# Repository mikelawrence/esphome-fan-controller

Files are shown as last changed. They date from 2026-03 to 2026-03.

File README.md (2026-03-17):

# ESPHome RGBCCT LED Controller

<p align="center">
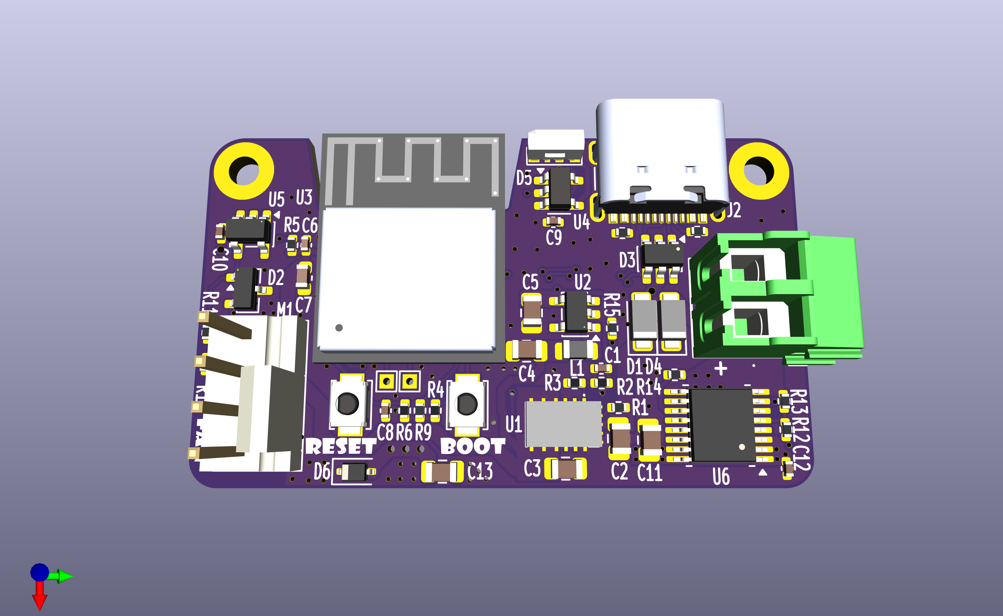
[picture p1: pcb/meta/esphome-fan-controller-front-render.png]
  
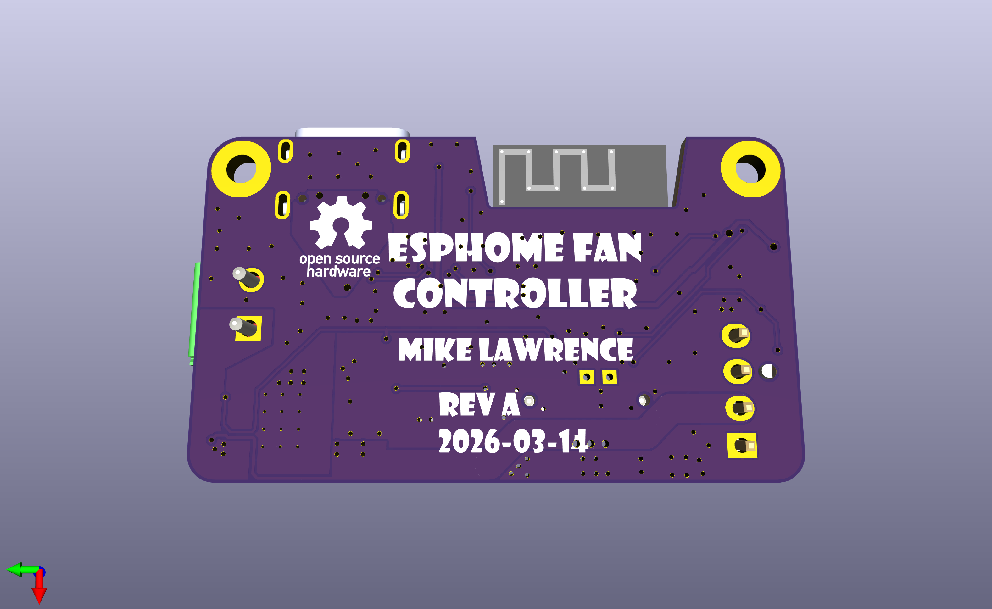
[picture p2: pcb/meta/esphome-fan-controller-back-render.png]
  
</p>

This is a simple ESP32-C3 based fan controller design to support 4-pin computer fans from 5V to 24V at up to 2 amps. Fan tachometer is supported.

## Web Installation

Goto [Github Pages](https://mikelawrence.github.io/esphome-fan-controller/) if you want to install a prebuilt image and receive automatic update notifications via Home Assistant.

## Status

* **Rev -:** Ordered boards from JLCPCB. Ordered parts from Mouser and Digikey. Board is assembled but there is a problem with the 5V Power Supply. Wait for Rev A.
* **Rev A:** Coming soon!

## Schematic

<p align="center">
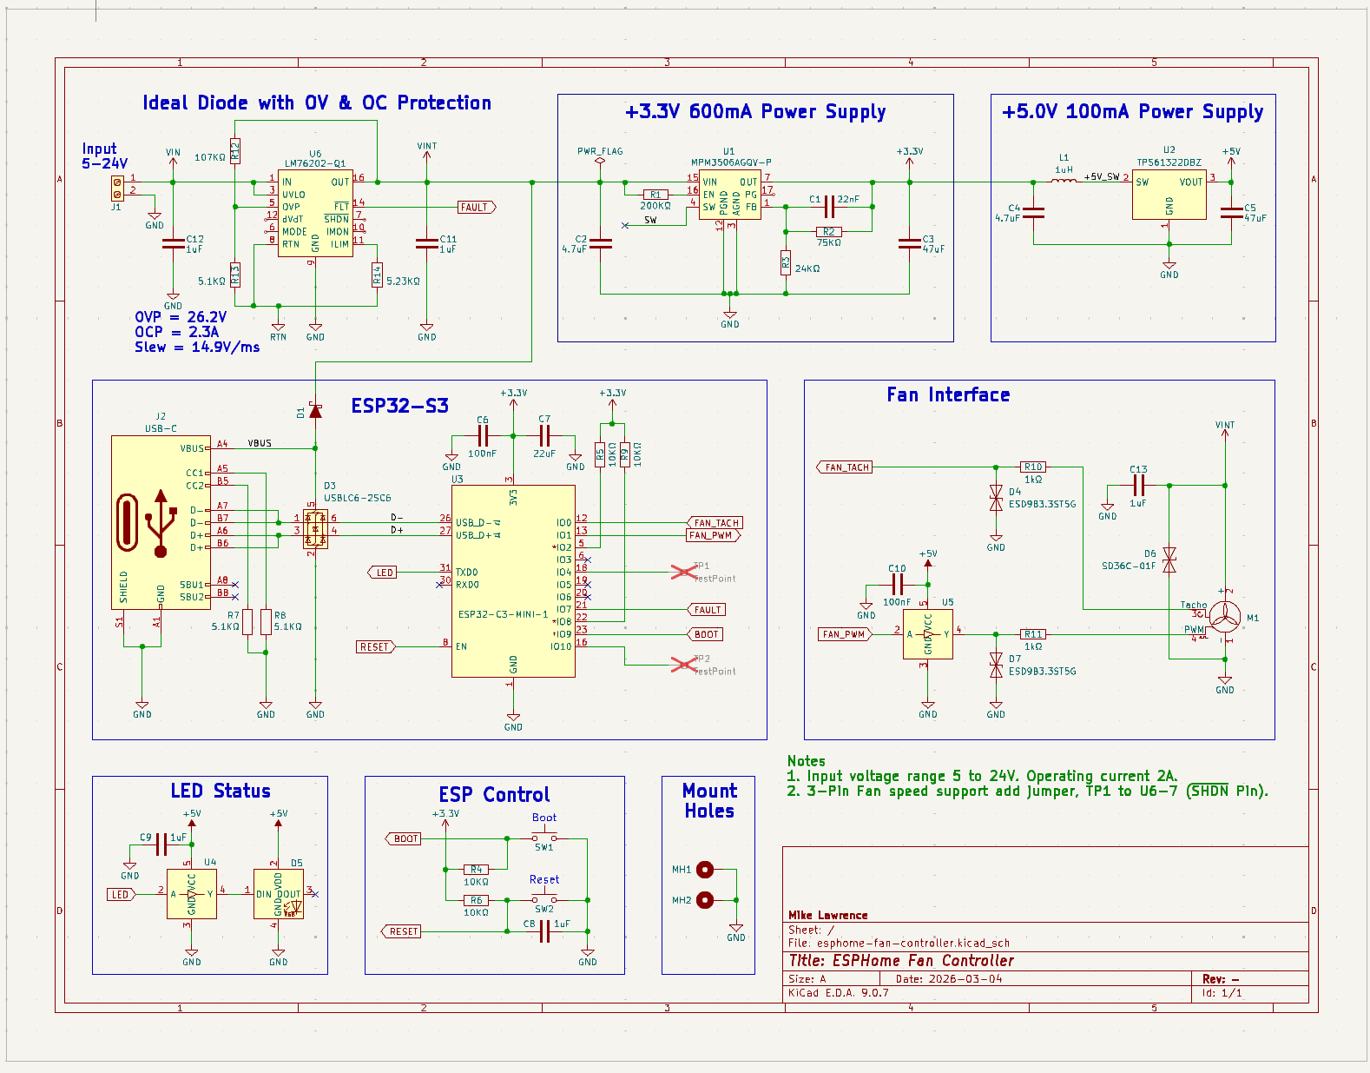
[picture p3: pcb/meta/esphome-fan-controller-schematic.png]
     <br />
    Schematic
</p>

## Bill of Materials

<p align="center">
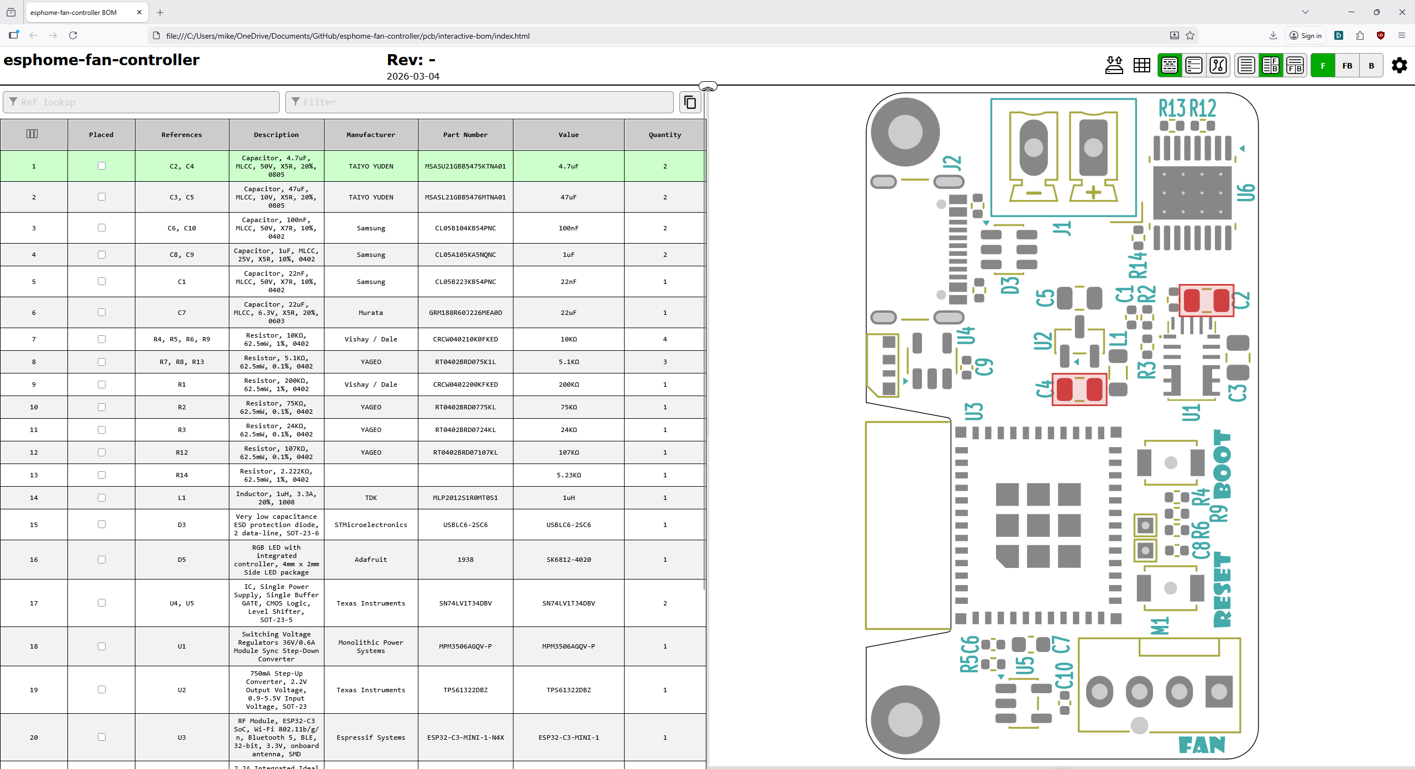
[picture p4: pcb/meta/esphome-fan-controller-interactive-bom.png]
     <br />
    Interactive BOM
</p>

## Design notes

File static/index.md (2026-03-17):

Sensor

# Web Installation

Use the button below to install pre-built firmware directly to your hardware via USB. You must use Google Chrome or Microsoft Edge to program your device. Firefox does not work.

| &nbsp; &nbsp; &nbsp; &nbsp; &nbsp; For 4-Pin Fans &nbsp; &nbsp; &nbsp; &nbsp; &nbsp; | &nbsp; &nbsp; &nbsp; &nbsp; &nbsp; For 3-Pin Fans &nbsp; &nbsp; &nbsp; &nbsp; &nbsp; |
| :---: | :---: |
| <esp-web-install-button manifest="firmware/fan-controller-4pin.manifest.json"></esp-web-install-button> | Coming Soon |

<script type="module" src="https://unpkg.com/esp-web-tools@10/dist/web/install-button.js?module"></script>

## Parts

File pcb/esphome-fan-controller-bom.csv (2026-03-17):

Qty | Reference | Value | Description | Datasheet | Footprint | DNP | Manufacturer | Part Number
1 | C1 | 22nF | Capacitor, 22nF, MLCC, 50V, X7R, 10%, 0402 | ~ | Capacitor_SMD:C_0402_1005Metric |  | Murata | GRM155R71H223KA12J
1 | C7 | 22uF | Capacitor, 22uF, MLCC, 6.3V, X5R, 20%, 0603 | ~ | Capacitor_SMD:C_0603_1608Metric |  | Murata | GRM188R60J226MEA0D
2 | C11,C13 | 1uF | Capacitor, 1uF, MLCC, 50V, X5R, 20%, 0805 | ~ | Capacitor_SMD:C_0805_2012Metric |  | YAGEO | CC0805MKY5V9BB105
2 | C2,C4 | 4.7uF | Capacitor, 4.7uF, MLCC, 50V, X5R, 20%, 0805 | ~ | Capacitor_SMD:C_0805_2012Metric |  | TAIYO YUDEN | MSASU21GBB5475KTNA01
2 | C3,C5 | 47uF | Capacitor, 47uF, MLCC, 10V, X5R, 20%, 0805 | ~ | Capacitor_SMD:C_0805_2012Metric |  | TAIYO YUDEN | MSASL21GBB5476MTNA01
3 | C6,C10,C12 | 100nF | Capacitor, 100nF, MLCC, 50V, X7R, 10%, 0402 | ~ | Capacitor_SMD:C_0402_1005Metric |  | Samsung | CL05B104KB54PNC
2 | C8,C9 | 1uF | Capacitor, 1uF, MLCC, 25V, X5R, 10%, 0402 | ~ | Capacitor_SMD:C_0402_1005Metric |  | Samsung | CL05A105KA5NQNC
1 | D2 | ESDS452 | 5.5-V Bi-Directional TVS Diode | https://www.ti.com/lit/ds/symlink/esds452.pdf | Package_TO_SOT_SMD:SOT-23 |  | Texas Instruments | ESDS452DBZR
1 | D3 | USBLC6-2SC6 | Very low capacitance ESD protection diode, 2 data-line, SOT-23-6 | https://www.st.com/resource/en/datasheet/usblc6-2.pdf | Package_TO_SOT_SMD:SOT-23-6 |  | STMicroelectronics | USBLC6-2SC6
1 | D5 | SK6812-4020 | RGB LED with integrated controller, 4mm x 2mm Side LED package | https://cdn-shop.adafruit.com/product-files/4691/4691_SK68XX_SIDE_REV.04_EN_1_.pdf | SK6812-4020:SK6812-4020 |  | Adafruit | 4691
1 | D6 | SD36C-01F | 36V, 450W Discrete Bidirectional TVS Diode, SOD-323 | https://www.littelfuse.com/~/media/electronics/datasheets/tvs_diode_arrays/littelfuse_tvs_diode_array_sd_c_datasheet.pdf.pdf | Diode_SMD:D_SOD-323 |  | Littelfuse | SD36C-01FTG
2 | D1,D4 | SS2FH6HM3/H | 40V 2A Schottky Barrier Rectifier Diode, SMF(DO-219AB) | https://www.vishay.com/docs/87731/ss2fh6.pdf | Diode_SMD:D_SMF |  | Vishay | SS2FH6HM3/H
1 | J1 | Screw_Terminal_01x02 | Generic screw terminal, single row, 01x02, script generated (kicad-library-utils/schlib/autogen/connector/) | https://www.phoenixcontact.com/en-us/products/printed-circuit-board-terminal-pta-15-2-35-1988956 | 1984769:1984769 |  | Phoenix Contact | 1988956
1 | J2 | USB-C | Connector, USB 2.0, 16P, Type-C, Receptacle | https://www.usb.org/sites/default/files/documents/usb_type-c.zip | TYPE-C-31-M-12:HRO_TYPE-C-31-M-12 |  | Phoenix Contact | 1332645
1 | L1 | 1uH | Inductor, 1uH, 3.3A, 20%, 1008 | ~ | Inductor_SMD:L_0805_2012Metric |  | TDK | MLP2012S1R0MT0S1
1 | M1 | Fan_CPU_4pin | CPU Fan, tacho output, PWM input, 4-pin connector | http://www.formfactors.org/developer%5Cspecs%5Crev1_2_public.pdf | Connector:FanPinHeader_1x04_P2.54mm_Vertical |  | Molex | 47053-1000
1 | R1 | 200KΩ | Resistor, 200KΩ, 62.5mW,100PPM, 1%, 0402 | ~ | Resistor_SMD:R_0402_1005Metric |  | Vishay / Dale | CRCW0402200KFKED
1 | R2 | 75KΩ | Resistor, 75KΩ, 62.5mW, 25PPM, 0.1%, 0402 | ~ | Resistor_SMD:R_0402_1005Metric |  | YAGEO | RT0402BRD0775KL
1 | R3 | 24KΩ | Resistor, 24KΩ, 62.5mW, 25PPM, 0.1%, 0402 | ~ | Resistor_SMD:R_0402_1005Metric |  | YAGEO | RT0402BRD0724KL
1 | R12 | 107KΩ | Resistor, 107KΩ, 62.5mW, 25PPM, 0.1%, 0402 | ~ | Resistor_SMD:R_0402_1005Metric |  | YAGEO | RT0402BRD07107KL
1 | R14 | 5.23KΩ | Resistor, 5.23KΩ, 62.5mW, 25PPM, 0.1%, 0402 | ~ | Resistor_SMD:R_0402_1005Metric |  | YAGEO | RT0402BRD075K23L
2 | R10,R11 | 1kΩ | Resistor, 1KΩ, 62.5mW,100PPM, 1%, 0402 | ~ | Resistor_SMD:R_0402_1005Metric |  | Vishay / Dale | CRCW04021K0FKED
5 | R4,R5,R6,R9,R15 | 10KΩ | Resistor, 10KΩ, 62.5mW,100PPM, 1%, 0402 | ~ | Resistor_SMD:R_0402_1005Metric |  | Vishay / Dale | CRCW040210K0FKED
3 | R7,R8,R13 | 5.1KΩ | Resistor, 5.1KΩ, 62.5mW, 25PPM, 0.1%, 0402 | ~ | Resistor_SMD:R_0402_1005Metric |  | YAGEO | RT0402BRD075K1L
2 | SW1,SW2 | ~ | Switch, SMD | https://omronfs.omron.com/en_US/ecb/products/pdf/en-b3u.pdf | Button_Switch_SMD:SW_SPST_B3U-1000P-B |  | Omron | B3U-1000P
2 | TP1,TP2 | TestPoint | Test Point | ~ | TestPoint:TestPoint_THTPad_1.0x1.0mm_Drill0.5mm | DNP
1 | U1 | MPM3506AGQV-P | Switching Voltage Regulators 36V/0.6A Module Sync Step-Down Converter | https://www.monolithicpower.com/pub/media/document/MPM3506A_r1.0.pdf | MPM3506A:QFN-19 |  | Monolithic Power Systems | MPM3506AGQV-P
1 | U2 | TPS613222ADBV | 1.8A Step-Up Converter, 5V Output Voltage, 0.9-5.5V Input Voltage, SOT-23-5 | http://www.ti.com/lit/ds/symlink/tps61322.pdf | Package_TO_SOT_SMD:SOT-23-5 |  | Texas Instruments | TPS613222ADBVR
1 | U3 | ESP32-C3-MINI-1 | RF Module, ESP32-C3 SoC, Wi-Fi 802.11b/g/n, Bluetooth 5, BLE, 32-bit, 3.3V, onboard antenna, SMD | https://documentation.espressif.com/esp32-c3-mini-1_datasheet_en.pdf | ESP32-C3-MINI:ESP32-C3-MINI-1-N4X |  | Espressif Systems | ESP32-C3-MINI-1-N4X
1 | U6 | LM76202-Q1 | 2.2A Integrated Ideal Diode with Overvoltage and Overcurrent Protection, 4.2 to 60V Input Voltage, HTSSOP-16 | https://www.ti.com/lit/ds/symlink/lm76202-q1.pdf | Package_SO:HTSSOP-16-1EP_4.4x5mm_P0.65mm_EP3.4x5mm_Mask2.66x2.46mm_ThermalVias |  | Texas Instruments | LM76202QPWPRQ1
2 | U4,U5 | SN74LV1T34DBV | IC, Single Power Supply, Single Buffer GATE, CMOS Logic, Level Shifter, SOT-23-5 | https://www.ti.com/lit/ds/symlink/sn74lv1t34.pdf | Package_TO_SOT_SMD:SOT-23-5 |  | Texas Instruments | SN74LV1T34DBV

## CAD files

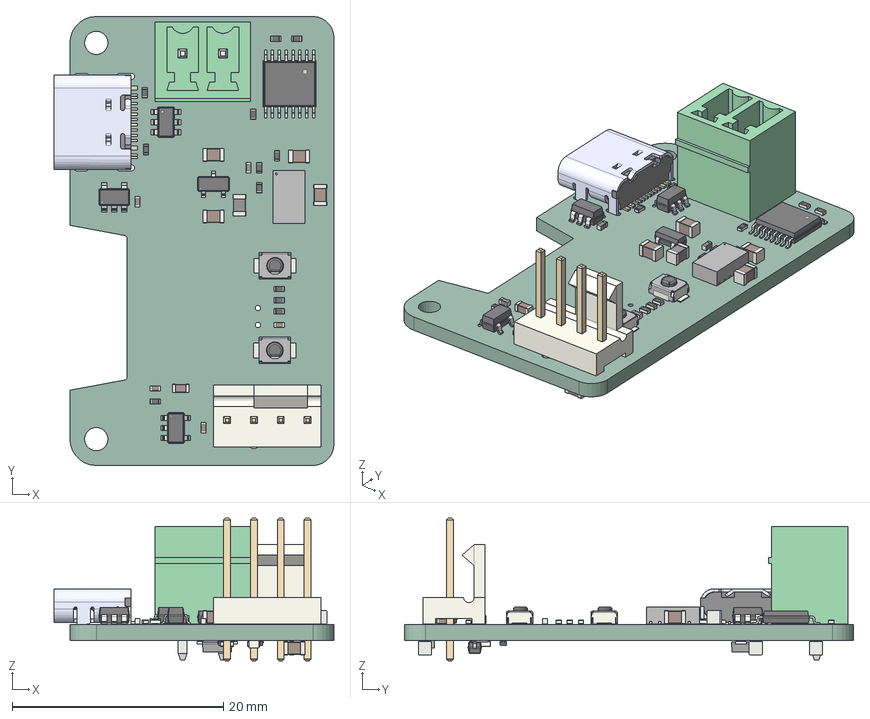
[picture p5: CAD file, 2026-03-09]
pcb/meta/esphome-fan-controller-3d-model.step
26.5 x 42.5 x 13.5 mm
FanPinHeader_1x04_P2.54mm_Vertical
R_0402_1005Metric x 12
C_0603_1608Metric
C_0805_2012Metric x 7
SOT-23-5 x 2
TYPE-C-31-M-12
SOT-23-6
C_0402_1005Metric x 5
HTSSOP-16-1EP_4.4x5mm_P0.65mm_EP3.4x5mm_Mask2.66x2.46mm
SW_SPST_B3U-1000P-B x 2
PhoenixContact_MCV_1,5_2-G-3.81_1x02_P3.81mm_Vertical
L_0805_2012Metric
SOT-23
D_SOD-923 x 2
D_SOD-323
R_0805_2012Metric x 2
D_SMF
esphome-fan-controller_PCB

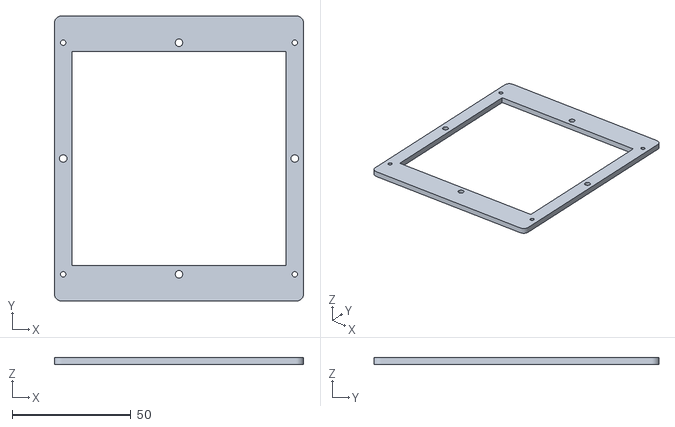
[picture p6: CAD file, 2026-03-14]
pcb/stencil/Jig/Stencil Support Frame.stl
105.0 x 120.0 x 3.00

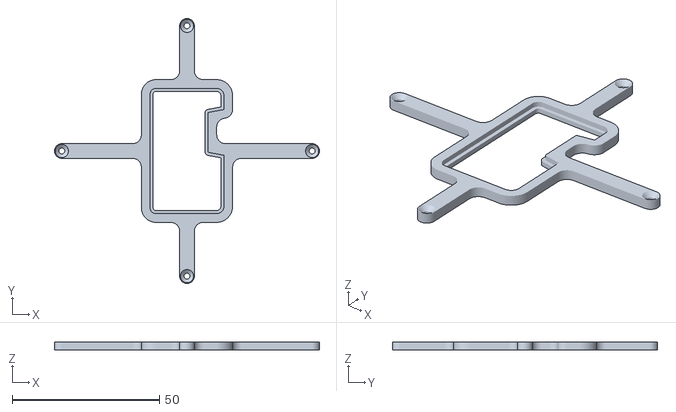
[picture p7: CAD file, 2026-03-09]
pcb/stencil/topRegister.stl
90.0 x 90.0 x 2.85

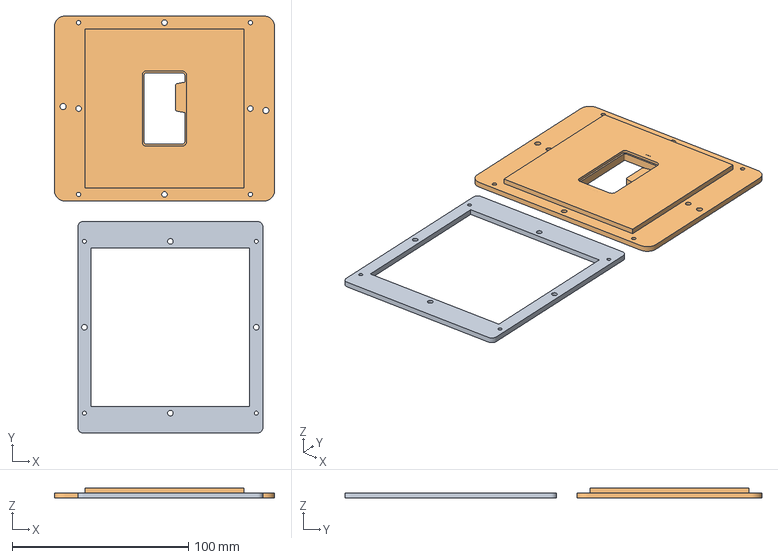
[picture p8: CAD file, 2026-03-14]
pcb/stencil/Jig/Stencil Jig.3mf
125.0 x 236.6 x 5.85 mm
Stencil Support Ring.stl
Stencil Support Base.stl

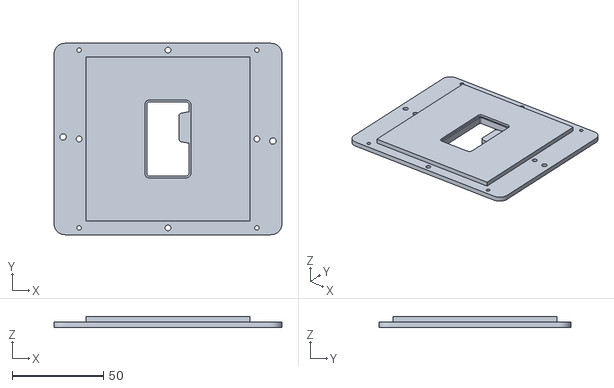
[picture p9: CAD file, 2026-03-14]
pcb/stencil/Jig/Stencil Support Base.stl
125.0 x 105.0 x 5.85

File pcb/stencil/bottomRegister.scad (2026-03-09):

// Generated by SolidPython 1.1.3 on 2026-03-04 21:28:39


scale(v = 0.0000010000) {
	translate(v = [-139250000, -43900000, 0]) {
		difference() {
			linear_extrude(convexity = 10, height = 2850000) {
				polygon(points = [[141693022.9765343964, 876584.0577139166], [141693017.3056575358, 876560.1787741705], [141651296.7346810102, 710002.3230492133], [141651290.4794936180, 709978.5904716417], [141641492.7769555748, 674574.2427555623], [141641478.5290703773, 674527.2737726383], [141629955.4192904830, 639646.3226207905], [141629947.4351750612, 639623.1145077969], [141572102.2354335189, 477956.6114429196], [141572093.6841671765, 477933.6062597772], [141558872.9273265898, 443660.0829398052], [141558854.1442834437, 443614.7366623346], [141543967.5903429687, 410031.2090928535], [141543957.3698804080, 410008.8953134285], [141470544.6222684979, 254790.6817084925], [141470533.8572765589, 254768.6254722681], [141454017.3692491055, 221955.9993139049], [141453994.2319390178, 221912.7124513298], [141435887.5994900763, 189950.0361928967], [141435875.2411089838, 189928.8316409335], [141347601.9505185187, 42653.7437455194], [141347589.0754737556, 42632.8488698249], [141327935.9190671444, 11597.1233987124], [141327908.6503150463, 11556.3128271826], [141306756.3161259294, -18477.6940756445], [141306741.9388442636, -18497.5851887195], [141204458.2253189385, -156411.2077693982], [141204443.3642150760, -156430.7400554862], [141181842.8100692332, -185390.6738366023], [141181811.6724881232, -185428.6150889755], [141157817.3451008797, -213244.7087303483], [141157801.0873797238, -213263.0948422418], [141042491.9989932179, -340487.0685335643], [141042475.2949508131, -340505.0501234545], [141017144.9987581670, -367110.2922195609], [141017110.2922199667, -367144.9987577752], [140990505.0501228571, -392475.2949513569], [140990487.0685329437, -392491.9989937603], [140863263.0948421657, -507801.0873797789], [140863244.7087302804, -507817.3451009306], [140835428.6150889695, -531811.6724881203], [140835390.6738365889, -531842.8100692400], [140806430.7400557697, -554443.3642148786], [140806411.2077696919, -554458.2253187329], [140668497.5851880610, -656741.9388447497], [140668477.6940749884, -656756.3161264205], [140638443.6871729195, -677908.6503150287], [140638402.8766013980, -677935.9190671270], [140607367.1511304677, -697589.0754735931], [140607346.2562547624, -697601.9505183435], [140460071.1683594286, -785875.2411087927], [140460049.9638074636, -785887.5994899011], [140428087.2875488997, -803994.2319389186], [140428044.0006863177, -804017.3692490055], [140395231.3745270669, -820533.8572769017], [140395209.3182908595, -820544.6222688297], [140239991.1046866775, -893957.3698803785], [140239968.7909072340, -893967.5903429586], [140206385.2633377910, -908854.1442834048], [140206339.9170603454, -908872.9273265359], [140172066.3937401175, -922093.6841672380], [140172043.3885569572, -922102.2354335863], [140010376.8854922950, -979947.4351750311], [140010353.6773793101, -979955.4192904411], [139975472.7262275219, -991478.5290703166], [139975425.7572445869, -991492.7769555190], [139940021.4095280170, -1001290.4794937035], [139939997.6769504547, -1001296.7346811026], [139773439.8212260008, -1043017.3056575025], [139773415.9422862530, -1043022.9765343465], [139737573.4901797473, -1051071.6683072061], [139737525.3508283496, -1051081.2438195567], [139701331.1419386566, -1057361.5348235844], [139701306.9105243385, -1057365.4336911601], [139531461.7453398705, -1082559.5839974100], [139531437.4255406260, -1082562.8870220440], [139494978.6548869312, -1087059.6474861868], [139494929.8087753356, -1087064.4584082668], [139458294.3087296486, -1089766.8552426763], [139458269.8118403852, -1089768.3602422029], [139286773.0389835238, -1098193.4564382904], [139286748.5125377178, -1098194.3598007814], [139250024.5412285030, -1099095.8826947904], [139249975.4587714374, -1099095.8826947904], [139213251.4874623120, -1098194.3598007835], [139213226.9610165060, -1098193.4564382925], [139041730.1881595552, -1089768.3602422005], [139041705.6912702918, -1089766.8552426740], [139005070.1912246644, -1087064.4584082672], [139005021.3451130688, -1087059.6474861873], [138968562.5744596124, -1082562.8870220762], [138968538.2546603680, -1082559.5839974422], [138798693.0894754231, -1057365.4336911200], [138798668.8580611050, -1057361.5348235441], [138762474.6491717100, -1051081.2438195648], [138762426.5098203123, -1051071.6683072145], [138726584.0577137470, -1043022.9765343465], [138726560.1787739992, -1043017.3056575025], [138560002.3230495453, -1001296.7346811026], [138559978.5904719830, -1001290.4794937035], [138524574.2427554131, -991492.7769555190], [138524527.2737724781, -991478.5290703166], [138489646.3226206899, -979955.4192904411], [138489623.1145077050, -979947.4351750311], [138327956.6114432812, -922102.2354336667], [138327933.6062601209, -922093.6841673184], [138293660.0829394758, -908872.9273264585], [138293614.7366620302, -908854.1442833274], [138260031.2090924680, -893967.5903428259], [138260008.8953130245, -893957.3698802458], [138104790.6817094088, -820544.6222689716], [138104768.6254732013, -820533.8572770435], [138071955.9993135929, -804017.3692489583], [138071912.7124510109, -803994.2319388717], [138039950.0361929238, -785887.5994901358], [138039928.8316409588, -785875.2411090273], [137892653.7437450290, -697601.9505182250], [137892632.8488693237, -697589.0754734743], [137861597.1233987510, -677935.9190672240], [137861556.3128272295, -677908.6503151262], [137831522.3059248924, -656756.3161263420], [137831502.4148118198, -656741.9388446709], [137693588.7922302485, -554458.2253186895], [137693569.2599441707, -554443.3642148355], [137664609.3261635005, -531842.8100693221], [137664571.3849111199, -531811.6724882020], [137636755.2912700772, -507817.3451012222], [137636736.9051581919, -507801.0873800708], [137509512.9314664006, -392491.9989931565], [137509494.9498764873, -392475.2949507528], [137482889.7077801228, -367144.9987578539], [137482855.0012419224, -367110.2922196402], [137457524.7050491869, -340505.0501234548], [137457508.0010067821, -340487.0685335643], [137342198.9126202464, -213263.0948421923], [137342182.6548990905, -213244.7087302993], [137318188.3275119066, -185428.6150890225], [137318157.1899307966, -185390.6738366488], [137295556.6357848942, -156430.7400554426], [137295541.7746810317, -156411.2077693549], [137193258.0611552894, -18497.5851881228], [137193243.6838736236, -18477.6940750481], [137172091.3496848941, 11556.3128272051], [137172064.0809327960, 11597.1233987360], [137152410.9245266914, 42632.8488691091], [137152398.0494819283, 42653.7437448027], [137064124.7588908374, 189928.8316412119], [137064112.4005097449, 189950.0361931753], [137046005.7680612504, 221912.7124508230], [137045982.6307511628, 221955.9993133984], [137029466.1427230835, 254768.6254730366], [137029455.3777311444, 254790.6817092606], [136956042.6301194429, 410008.8953137114], [136956032.4096568823, 410031.2090931371], [136941145.8557167649, 443614.7366618710], [136941127.0726736188, 443660.0829393408], [136927906.3158324957, 477933.6062606899], [136927897.7645661533, 477956.6114438325], [136870052.5648249686, 639623.1145077337], [136870044.5807095468, 639646.3226207269], [136858521.4709296227, 674527.2737726289], [136858507.2230444252, 674574.2427555531], [136848709.5205063522, 709978.5904717175], [136848703.2653189600, 710002.3230492891], [136806982.6943424344, 876560.1787742114], [136806977.0234655738, 876584.0577139584], [136798928.3316927552, 912426.5098203920], [136798918.7561804056, 912474.6491717874], [136792638.4651765525, 948668.8580603324], [136792634.5663089752, 948693.0894746381], [136767429.3645716608, 1118612.7573557924], [136767426.0676938295, 1118637.0273283769], [136762936.6630683243, 1155021.1230146892], [136762931.8570905626, 1155069.8687487294], [136760229.4721207321, 1191630.1516820237], [136760227.9659038782, 1191654.5982008670], [136751821.3497653604, 1362076.8715436186], [136751820.4389982820, 1362101.4981856763], [136750000.3036504984, 1435943.3814674343], [136750000.0000000000, 1435968.0230743641], [136750000.0000000000, 16651368.8236737140], [136746387.8566702306, 16798523.1400358044], [136735561.0301870406, 16945310.7641990595], [136717545.2978813648, 17091390.4005906694], [136692384.0542091131, 17236410.1875022128], [136660137.9050047994, 17380020.8160795346], [136620884.5214995146, 17521876.3717065156], [136574718.4532345235, 17661635.1672084108], [136521750.9003214240, 17798960.5658680983], [136462109.4455913305, 17933521.7922925167], [136395937.7472908199, 18064994.7291384302], [136323395.1930487752, 18193062.6978226602], [136244656.5159615874, 18317417.2213010155], [136159911.3737139404, 18437758.7670961730], [136069363.8917499781, 18553797.4687823169], [135973232.1715979874, 18665253.8241842054], [135871747.7655279338, 18771859.3686155453], [135765155.1188133657, 18873357.3215276524], [135653710.9809363484, 18969503.2050166130], [135537683.7871559262,
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

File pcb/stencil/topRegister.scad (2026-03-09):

// Generated by SolidPython 1.1.3 on 2026-03-04 21:28:20


scale(v = 0.0000010000) {
	translate(v = [-139250000, -43900000, 0]) {
		difference() {
			linear_extrude(convexity = 10, height = 2850000) {
				polygon(points = [[136806977.0234656036, 876584.0577139166], [136806982.6943424642, 876560.1787741705], [136848703.2653189898, 710002.3230492133], [136848709.5205063820, 709978.5904716417], [136858507.2230444252, 674574.2427555623], [136858521.4709296227, 674527.2737726383], [136870044.5807095170, 639646.3226207905], [136870052.5648249388, 639623.1145077969], [136927897.7645664811, 477956.6114429196], [136927906.3158328235, 477933.6062597772], [136941127.0726734102, 443660.0829398052], [136941145.8557165563, 443614.7366623346], [136956032.4096570313, 410031.2090928535], [136956042.6301195920, 410008.8953134285], [137029455.3777315021, 254790.6817084925], [137029466.1427234411, 254768.6254722681], [137045982.6307508945, 221955.9993139049], [137046005.7680609822, 221912.7124513298], [137064112.4005099237, 189950.0361928967], [137064124.7588910162, 189928.8316409335], [137152398.0494814813, 42653.7437455194], [137152410.9245262444, 42632.8488698249], [137172064.0809328556, 11597.1233987124], [137172091.3496849537, 11556.3128271826], [137193243.6838740706, -18477.6940756445], [137193258.0611557364, -18497.5851887195], [137295541.7746810615, -156411.2077693982], [137295556.6357849240, -156430.7400554862], [137318157.1899307668, -185390.6738366023], [137318188.3275118768, -185428.6150889755], [137342182.6548991203, -213244.7087303483], [137342198.9126202762, -213263.0948422418], [137457508.0010067821, -340487.0685335643], [137457524.7050491869, -340505.0501234545], [137482855.0012418330, -367110.2922195609], [137482889.7077800333, -367144.9987577752], [137509494.9498771429, -392475.2949513569], [137509512.9314670563, -392491.9989937603], [137636736.9051578343, -507801.0873797789], [137636755.2912697196, -507817.3451009306], [137664571.3849110305, -531811.6724881203], [137664609.3261634111, -531842.8100692400], [137693569.2599442303, -554443.3642148786], [137693588.7922303081, -554458.2253187329], [137831502.4148119390, -656741.9388447497], [137831522.3059250116, -656756.3161264205], [137861556.3128270805, -677908.6503150287], [137861597.1233986020, -677935.9190671270], [137892632.8488695323, -697589.0754735931], [137892653.7437452376, -697601.9505183435], [138039928.8316405714, -785875.2411087927], [138039950.0361925364, -785887.5994899011], [138071912.7124511003, -803994.2319389186], [138071955.9993136823, -804017.3692490055], [138104768.6254729331, -820533.8572769017], [138104790.6817091405, -820544.6222688297], [138260008.8953133225, -893957.3698803785], [138260031.2090927660, -893967.5903429586], [138293614.7366622090, -908854.1442834048], [138293660.0829396546, -908872.9273265359], [138327933.6062598825, -922093.6841672380], [138327956.6114430428, -922102.2354335863], [138489623.1145077050, -979947.4351750311], [138489646.3226206899, -979955.4192904411], [138524527.2737724781, -991478.5290703166], [138524574.2427554131, -991492.7769555190], [138559978.5904719830, -1001290.4794937035], [138560002.3230495453, -1001296.7346811026], [138726560.1787739992, -1043017.3056575025], [138726584.0577137470, -1043022.9765343465], [138762426.5098202527, -1051071.6683072061], [138762474.6491716504, -1051081.2438195567], [138798668.8580613434, -1057361.5348235844], [138798693.0894756615, -1057365.4336911601], [138968538.2546601295, -1082559.5839974100], [138968562.5744593740, -1082562.8870220440], [139005021.3451130688, -1087059.6474861868], [139005070.1912246644, -1087064.4584082668], [139041705.6912703514, -1089766.8552426763], [139041730.1881596148, -1089768.3602422029], [139213226.9610164762, -1098193.4564382904], [139213251.4874622822, -1098194.3598007814], [139249975.4587714970, -1099095.8826947904], [139250024.5412285626, -1099095.8826947904], [139286748.5125376880, -1098194.3598007835], [139286773.0389834940, -1098193.4564382925], [139458269.8118404448, -1089768.3602422005], [139458294.3087297082, -1089766.8552426740], [139494929.8087753356, -1087064.4584082672], [139494978.6548869312, -1087059.6474861873], [139531437.4255403876, -1082562.8870220762], [139531461.7453396320, -1082559.5839974422], [139701306.9105245769, -1057365.4336911200], [139701331.1419388950, -1057361.5348235441], [139737525.3508282900, -1051081.2438195648], [139737573.4901796877, -1051071.6683072145], [139773415.9422862530, -1043022.9765343465], [139773439.8212260008, -1043017.3056575025], [139939997.6769504547, -1001296.7346811026], [139940021.4095280170, -1001290.4794937035], [139975425.7572445869, -991492.7769555190], [139975472.7262275219, -991478.5290703166], [140010353.6773793101, -979955.4192904411], [140010376.8854922950, -979947.4351750311], [140172043.3885567188, -922102.2354336667], [140172066.3937398791, -922093.6841673184], [140206339.9170605242, -908872.9273264585], [140206385.2633379698, -908854.1442833274], [140239968.7909075320, -893967.5903428259], [140239991.1046869755, -893957.3698802458], [140395209.3182905912, -820544.6222689716], [140395231.3745267987, -820533.8572770435], [140428044.0006864071, -804017.3692489583], [140428087.2875489891, -803994.2319388717], [140460049.9638070762, -785887.5994901358], [140460071.1683590412, -785875.2411090273], [140607346.2562549710, -697601.9505182250], [140607367.1511306763, -697589.0754734743], [140638402.8766012490, -677935.9190672240], [140638443.6871727705, -677908.6503151262], [140668477.6940751076, -656756.3161263420], [140668497.5851881802, -656741.9388446709], [140806411.2077697515, -554458.2253186895], [140806430.7400558293, -554443.3642148355], [140835390.6738364995, -531842.8100693221], [140835428.6150888801, -531811.6724882020], [140863244.7087299228, -507817.3451012222], [140863263.0948418081, -507801.0873800708], [140990487.0685335994, -392491.9989931565], [140990505.0501235127, -392475.2949507528], [141017110.2922198772, -367144.9987578539], [141017144.9987580776, -367110.2922196402], [141042475.2949508131, -340505.0501234548], [141042491.9989932179, -340487.0685335643], [141157801.0873797536, -213263.0948421923], [141157817.3451009095, -213244.7087302993], [141181811.6724880934, -185428.6150890225], [141181842.8100692034, -185390.6738366488], [141204443.3642151058, -156430.7400554426], [141204458.2253189683, -156411.2077693549], [141306741.9388447106, -18497.5851881228], [141306756.3161263764, -18477.6940750481], [141327908.6503151059, 11556.3128272051], [141327935.9190672040, 11597.1233987360], [141347589.0754733086, 42632.8488691091], [141347601.9505180717, 42653.7437448027], [141435875.2411091626, 189928.8316412119], [141435887.5994902551, 189950.0361931753], [141453994.2319387496, 221912.7124508230], [141454017.3692488372, 221955.9993133984], [141470533.8572769165, 254768.6254730366], [141470544.6222688556, 254790.6817092606], [141543957.3698805571, 410008.8953137114], [141543967.5903431177, 410031.2090931371], [141558854.1442832351, 443614.7366618710], [141558872.9273263812, 443660.0829393408], [141572093.6841675043, 477933.6062606899], [141572102.2354338467, 477956.6114438325], [141629947.4351750314, 639623.1145077337], [141629955.4192904532, 639646.3226207269], [141641478.5290703773, 674527.2737726289], [141641492.7769555748, 674574.2427555531], [141651290.4794936478, 709978.5904717175], [141651296.7346810400, 710002.3230492891], [141693017.3056575656, 876560.1787742114], [141693022.9765344262, 876584.0577139584], [141701071.6683072448, 912426.5098203920], [141701081.2438195944, 912474.6491717874], [141707361.5348234475, 948668.8580603324], [141707365.4336910248, 948693.0894746381], [141732570.6354283392, 1118612.7573557924], [141732573.9323061705, 1118637.0273283769], [141737063.3369316757, 1155021.1230146892], [141737068.1429094374, 1155069.8687487294], [141739770.5278792679, 1191630.1516820237], [141739772.0340961218, 1191654.5982008670], [141748178.6502346396, 1362076.8715436186], [141748179.5610017180, 1362101.4981856763], [141749999.6963495016, 1435943.3814674343], [141750000.0000000000, 1435968.0230743641], [141750000.0000000000, 16651368.8236737140], [141753612.1433297694, 16798523.1400358044], [141764438.9698129594, 16945310.7641990595], [141782454.7021186352, 17091390.4005906694], [141807615.9457908869, 17236410.1875022128], [141839862.0949952006, 17380020.8160795346], [141879115.4785004854, 17521876.3717065156], [141925281.5467654765, 17661635.1672084108], [141978249.0996785760, 17798960.5658680983], [142037890.5544086695, 17933521.7922925167], [142104062.2527091801, 18064994.7291384302], [142176604.8069512248, 18193062.6978226602], [142255343.4840384126, 18317417.2213010155], [142340088.6262860596, 18437758.7670961730], [142430636.1082500219, 18553797.4687823169], [142526767.8284020126, 18665253.8241842054], [142628252.2344720662, 18771859.3686155453], [142734844.8811866343, 18873357.3215276524], [142846289.0190636516, 18969503.2050166130], [142962316.2128440738,
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

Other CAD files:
pcb/stencil/bottomRegister.stl

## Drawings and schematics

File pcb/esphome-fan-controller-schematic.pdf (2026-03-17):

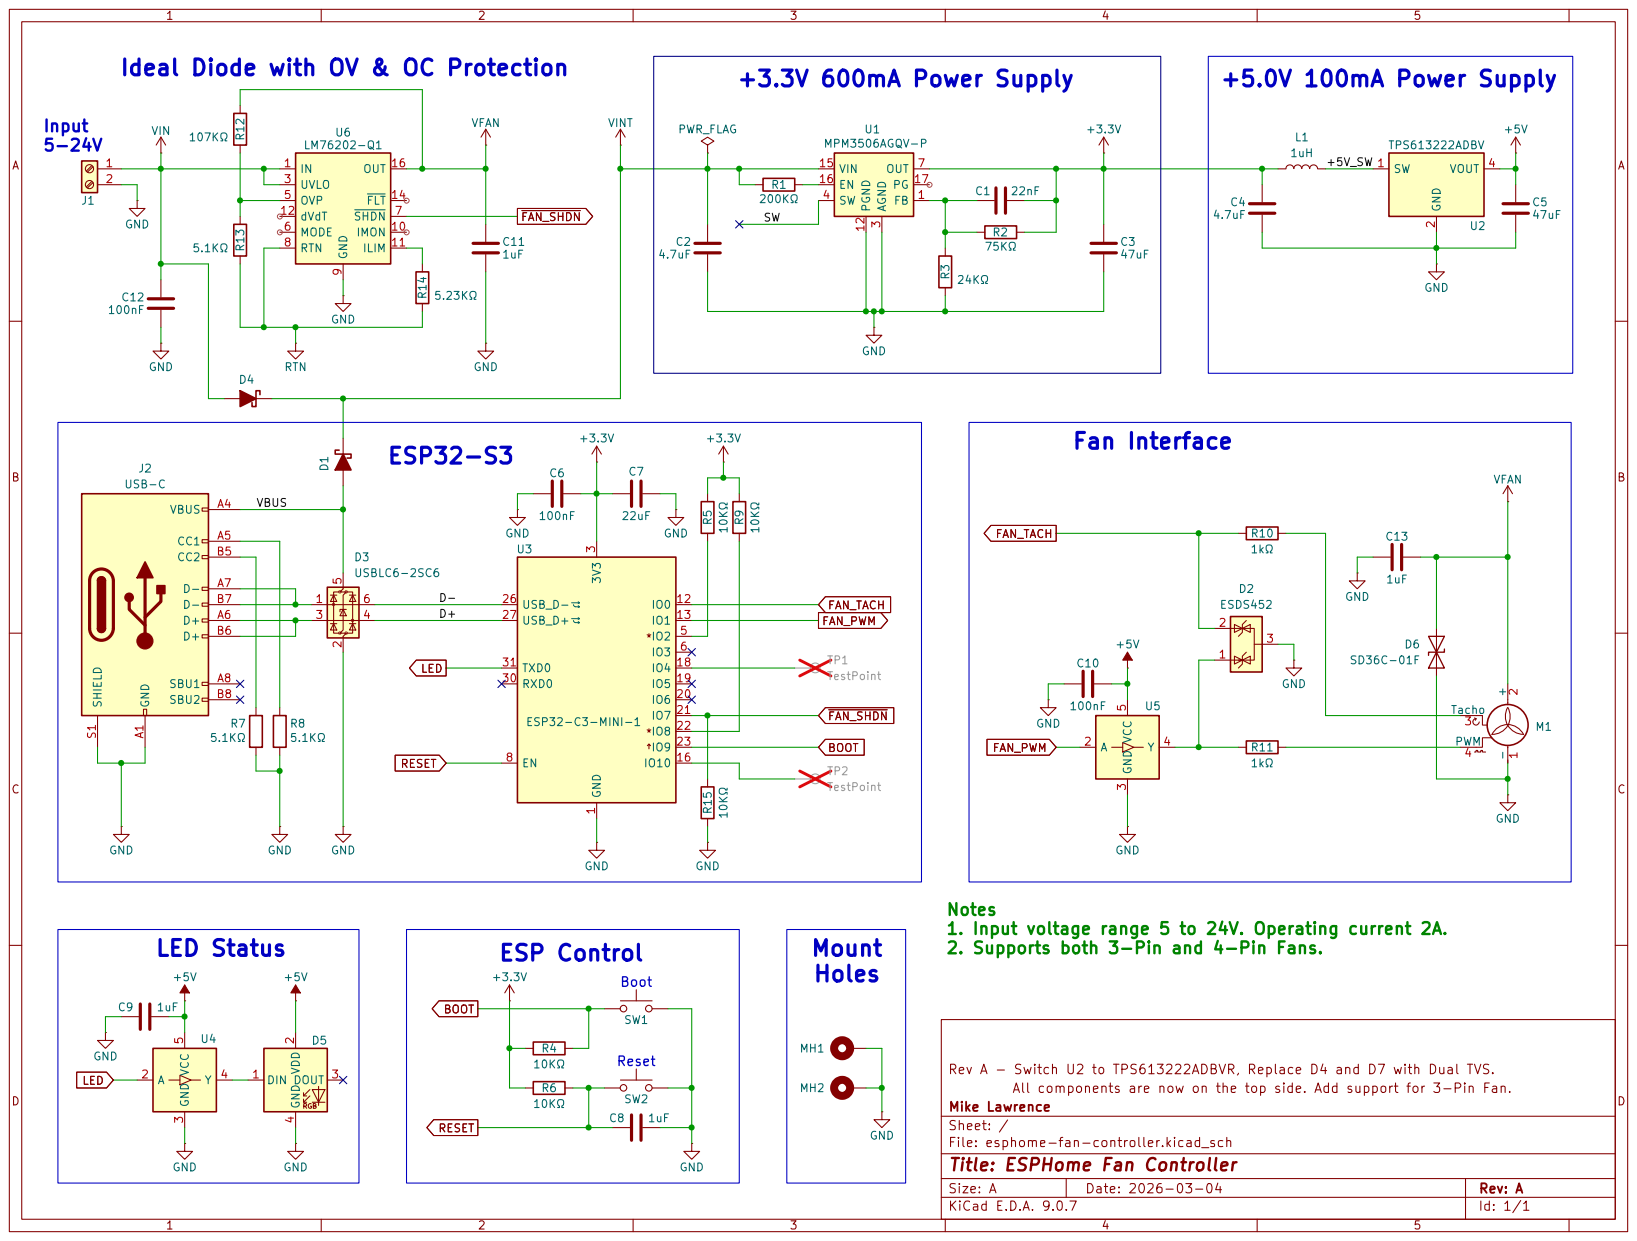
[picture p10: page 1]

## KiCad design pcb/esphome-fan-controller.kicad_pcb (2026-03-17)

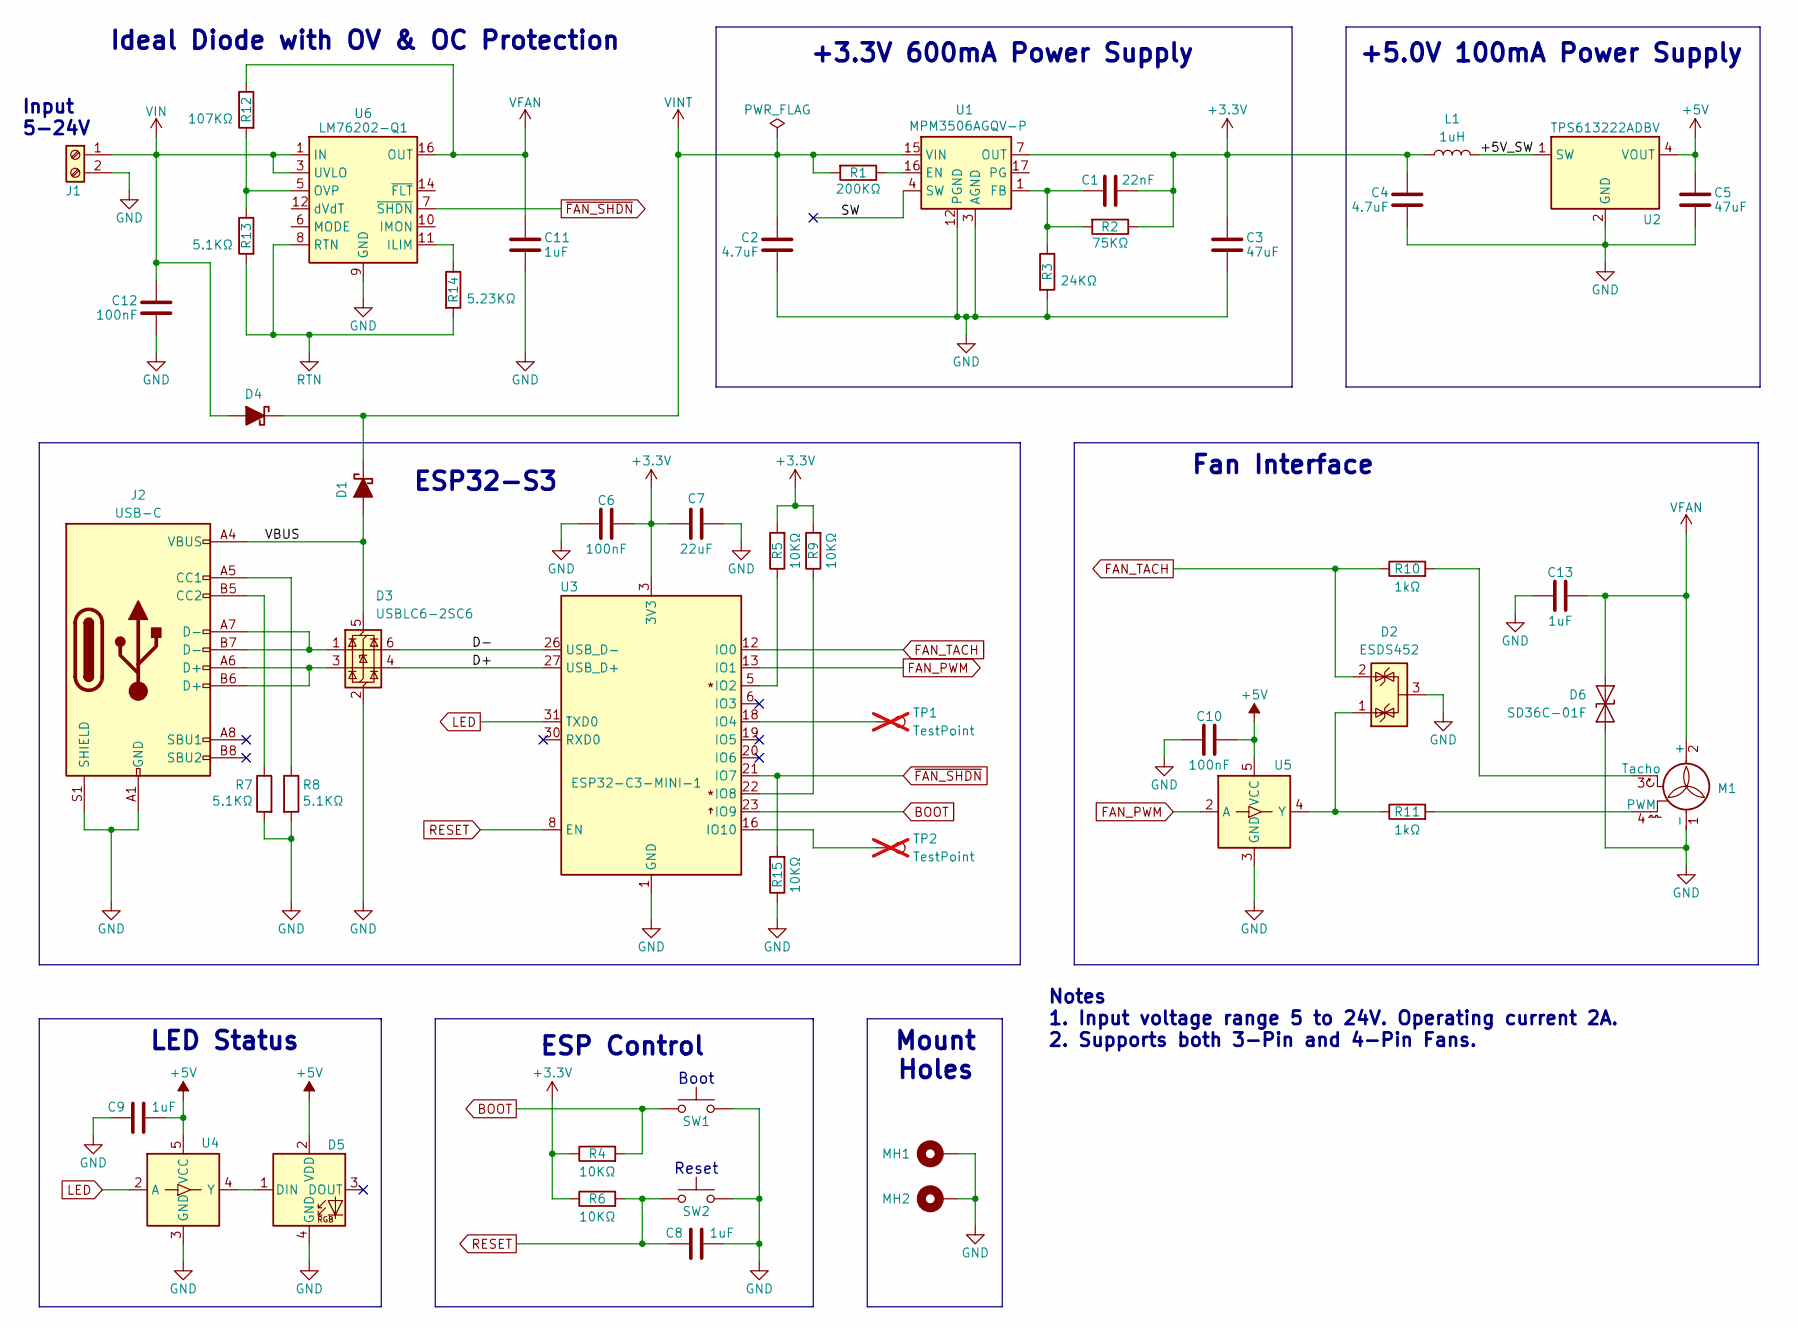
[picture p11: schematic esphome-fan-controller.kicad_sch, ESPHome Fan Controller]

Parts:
C1: 22nF; C_0402_1005Metric; Part Number GRM155R71H223KA12J
C2, C4: 4.7uF; C_0805_2012Metric; Part Number MSASU21GBB5475KTNA01
C3, C5: 47uF; C_0805_2012Metric; Part Number MSASL21GBB5476MTNA01
C6, C10, C12: 100nF; C_0402_1005Metric; Part Number CL05B104KB54PNC
C7: 22uF; C_0603_1608Metric; Part Number GRM188R60J226MEA0D
C8, C9: 1uF; C_0402_1005Metric; Part Number CL05A105KA5NQNC
C11, C13: 1uF; C_0805_2012Metric; Part Number CC0805MKY5V9BB105
D1, D4: SS2FH6HM3/H; D_SMF; Part Number SS2FH6HM3/H
D2: ESDS452; SOT-23; Part Number ESDS452DBZR
D3: USBLC6-2SC6; SOT-23-6; Part Number USBLC6-2SC6
D5: SK6812-4020; Part Number 4691
D6: SD36C-01F; D_SOD-323; Part Number SD36C-01FTG
J1: Screw_Terminal_01x02; 1984769; Part Number 1988956
J2: USB-C; HRO_TYPE-C-31-M-12; Part Number 1332645
L1: 1uH; L_0805_2012Metric; Part Number MLP2012S1R0MT0S1
M1: Fan_CPU_4pin; FanPinHeader_1x04_P2.54mm_Vertical; Part Number 47053-1000
MH1, MH2: MountingHole_2.2mm_M2_Pad
R1: 200KΩ; R_0402_1005Metric; Part Number CRCW0402200KFKED
R2: 75KΩ; R_0402_1005Metric; Part Number RT0402BRD0775KL
R3: 24KΩ; R_0402_1005Metric; Part Number RT0402BRD0724KL
R4, R5, R6, R9, R15: 10KΩ; R_0402_1005Metric; Part Number CRCW040210K0FKED
R7, R8, R13: 5.1KΩ; R_0402_1005Metric; Part Number RT0402BRD075K1L
R10, R11: 1kΩ; R_0402_1005Metric; Part Number CRCW04021K0FKED
R12: 107KΩ; R_0402_1005Metric; Part Number RT0402BRD07107KL
R14: 5.23KΩ; R_0402_1005Metric; Part Number RT0402BRD075K23L
SW1, SW2: SW_SPST_B3U-1000P-B; Part Number B3U-1000P
TP1, TP2: TestPoint; TestPoint_THTPad_1.0x1.0mm_Drill0.5mm; not fitted
U1: MPM3506AGQV-P; QFN-19; Part Number MPM3506AGQV-P; Mouser Part Number 946-MPM3506AGQV-P
U2: TPS613222ADBV; SOT-23-5; Part Number TPS613222ADBVR
U3: ESP32-C3-MINI-1; ESP32-C3-MINI-1-N4X; Part Number ESP32-C3-MINI-1-N4X
U4, U5: SN74LV1T34DBV; SOT-23-5; Part Number SN74LV1T34DBV
U6: LM76202-Q1; HTSSOP-16-1EP_4.4x5mm_P0.65mm_EP3.4x5mm_Mask2.66x2.46mm_The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; Part Number LM76202QPWPRQ1

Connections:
+3.3V: C1.2, C3.1, C4.1, C6.2, C7.1, L1.1, R2.1, R4.1, R5.2, R6.1, R9.2, U1.7 (OUT), U1.8 (OUT_2), U1.9 (OUT_3), U1.19 (OUT_4), U3.3 (3V3)
+5V: C5.1, C9.2, C10.2, D5.2 (VDD), U2.4 (VOUT), U4.5 (VCC), U5.5 (VCC)
/+5V_SW: L1.2, U2.1 (SW)
/D+: D3.4 (I/O2), U3.27 (USB_D+)
/D-: D3.6 (I/O1), U3.26 (USB_D-)
/SW: U1.4 (SW), U1.5 (SW_2), U1.6 (SW_3), U1.18 (SW_4)
/VBUS: D1.2 (A), D3.5 (VBUS), J2.A4 (VBUS), J2.B4 (VBUS)
BOOT: R4.2, SW1.2, U3.23 (IO9)
FAN_PWM: U3.13 (IO1), U5.2 (A)
FAN_TACH: D2.2 (K), R10.1, U3.12 (IO0)
GND: C2.2, C3.2, C4.2, C5.2, C6.1, C7.2, C8.2, C9.1, C10.1, C11.2, C12.2, C13.1, D2.3 (A), D3.2 (GND), D5.4 (GND), D6.1 (A1), J1.2, J2.A1 (GND), J2.B1 (GND), J2.S1 (SHIELD), M1.1 (-), MH1.1, MH2.1, R3.2, R7.2, R8.2, R15.1, SW1.1, SW2.1, U1.3 (AGND), U1.12 (PGND), U1.13 (PGND_2), U2.2 (GND), U3.1 (GND), U3.2 (GND), U3.11 (GND), U3.14 (GND), U3.36 (GND), U3.37 (GND), U3.38 (GND), U3.39 (GND), U3.40 (GND), U3.41 (GND), U3.42 (GND), U3.43 (GND), U3.44 (GND), U3.45 (GND), U3.46 (GND), U3.47 (GND), U3.48 (GND), U3.49 (GND), U3.50 (GND), U3.51 (GND), U3.52 (GND), U3.53 (GND), U4.3 (GND), U5.3 (GND), U6.9 (GND)
LED: U3.31 (TXD0), U4.2 (A)
unnamed: D3.1 (I/O1), J2.A7 (D-), J2.B7 (D-)
unnamed: D3.3 (I/O2), J2.A6 (D+), J2.B6 (D+)
unnamed: D5.1 (DIN), U4.4 (Y)
unnamed: J2.A5 (CC1), R8.1
unnamed: J2.B5 (CC2), R7.1
unnamed: M1.4 (PWM), R11.2
unnamed: M1.3 (Tacho), R10.2
unnamed: R1.1, U1.16 (EN)
unnamed: C1.1, R2.2, R3.1, U1.1 (FB)
unnamed: R5.1, U3.5 (IO2)
unnamed: TP1.1, U3.18 (IO4)
unnamed: R9.1, U3.22 (IO8)
unnamed: TP2.1, U3.16 (IO10)
unnamed: D2.1 (K), R11.1, U5.4 (Y)
unnamed: R14.1, U6.11 (ILIM)
unnamed: R12.2, R13.1, U6.5 (OVP)
RESET: C8.1, R6.2, SW2.2, U3.8 (EN)
RTN: R13.2, R14.2, U6.8 (RTN), U6.17 (RTN_1)
VFAN: C11.1, C13.2, D6.2 (A2), M1.2 (+), R12.1, U6.15 (OUT_2), U6.16 (OUT)
VIN: C12.1, D4.2 (A), J1.1, U6.1 (IN), U6.2 (IN_2), U6.3 (UVLO)
VINT: C2.1, D1.1 (K), D4.1 (K), R1.2, U1.15 (VIN)
~FAN_SHDN: R15.2, U3.21 (IO7), U6.7 (~SHDN)

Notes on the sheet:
Mount Holes
Notes 1. Input voltage range 5 to 24V. Operating current 2A. 2. Supports both 3-Pin and 4-Pin Fans.
Ideal Diode with OV & OC Protection
Boot
+5.0V 100mA Power Supply
ESP Control
LED Status
Input 5-24V
+3.3V 600mA Power Supply
ESP32-S3
Fan Interface
Reset

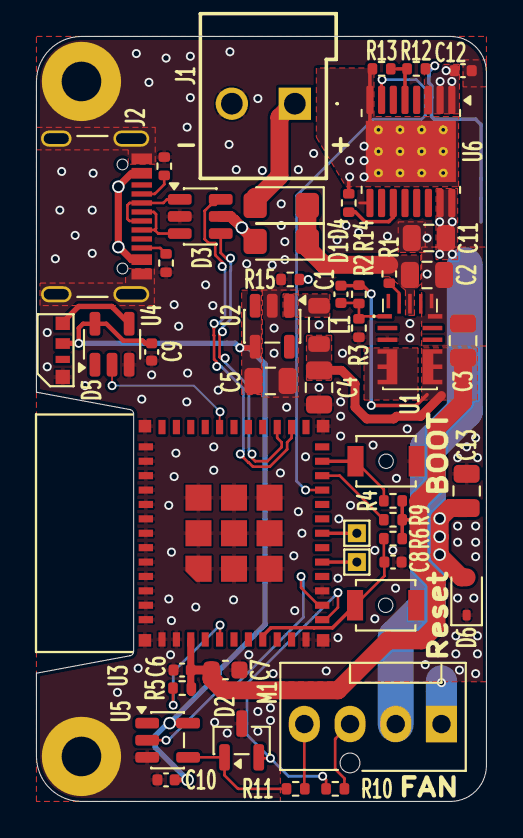
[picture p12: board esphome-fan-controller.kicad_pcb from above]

Board: 2 copper layers, 25.0 x 42.5 mm, 51 parts (1 on the bottom side), 34 nets.

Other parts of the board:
TEXT1: OSHW-Logo_5.7x6mm_SilkScreen

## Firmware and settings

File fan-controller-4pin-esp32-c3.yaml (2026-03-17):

substitutions:
  name: "fan-controller-4pin"
  friendly_name: "Fan Controller 4-Pin"

esphome:
  name: ${name}
  friendly_name: ${friendly_name}
  min_version: 2025.12.0
  name_add_mac_suffix: true
  on_boot:
    priority: 600
    then:
      - light.turn_on:
          id: led_status
          effect: "Rainbow"

esp32:
  variant: ESP32C3
  framework:
    type: esp-idf

logger:
  level: DEBUG

# API is a requirement of the dashboard import
# Grab a key from https://esphome.io/components/api.html
api:
#   encryption:
#     key:

# OTA is required for Over-the-Air updating
ota:
  - platform: esphome
    # password: !secret ota_password

# WiFi is required
wifi:
#   ssid: !secret wifi_ssid
#   password: !secret wifi_password
#   use_address: xxx.xxx.xxx.xxx

# Allows user to provision WiFi credentials with Bluetooth using Improv standard
esp32_improv:
  authorizer: none

# Allow user to provision WiFi credentials with USB port using Improv standard
improv_serial:

output:
  - platform: ledc
    pin: GPIO1
    id: fan_pwm
    frequency: 25000Hz # Standard for 4-pin PWM fans

light:
  - platform: esp32_rmt_led_strip
    id: led_status
    rgb_order: RGB
    pin: GPIO21
    num_leds: 1
    chipset: ws2812
    effects:
      - addressable_rainbow:
          name: Rainbow
          speed: 10
          width: 50
fan:
  - platform: speed
    output: fan_pwm
    name: "Fan"
    restore_mode: RESTORE_DEFAULT_ON

sensor:
  - platform: pulse_counter
    pin:
      number: GPIO0
      mode: INPUT_PULLUP
    name: "Fan RPM"
    unit_of_measurement: "RPM"
    icon: "mdi:fan"
    accuracy_decimals: 0
    filters:
      - multiply: 0.5
    update_interval: 10s

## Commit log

2026-03-09 Add logger to configuration yaml
    [fan-controller-esp32-c3.yaml]
2026-03-09 Switch to esphome build and update checkout version
2026-03-09 Reorg config files
    [fan-controller-esp32-c3.factory.yaml, fan-controller-esp32-c3.yaml]
2026-03-09 Correct config path
    [fan-controller-esp32-c3.factory.yaml]
2026-03-09 Trying to get Publish Firmware Action working
    [fan-controller-esp32-c3.factory.yaml, fan-controller-esp32-c3.yaml]
2026-03-09 Fix incorrect substitution
    [fan-controller-esp32-c3.factory.yaml]
2026-03-10 Switch to normal release
2026-03-10 Update notes on schematic
    [esphome-fan-controller.kicad_sch]
2026-03-11 Add fan pwm, fan rpm and status led
    [fan-controller-esp32-c3.yaml]
2026-03-11 Add PCB README back
2026-03-14 Fix dashboard_import pointing to invalid location.
    [fan-controller-esp32-c3.factory.yaml]
2026-03-14 Add Stencil Jig files
    [Stencil Jig.3mf, Stencil Support Base.stl, Stencil Support Frame.stl]
2026-03-14 Default Rainbow effect for Status LED
    [fan-controller-esp32-c3.yaml]
2026-03-14 Fix YAML error with rainbow light effect
    [fan-controller-esp32-c3.yaml]
2026-03-14 Create Release action now creates official release instead of pre-release
    [fan-controller-esp32-c3.factory.yaml]
2026-03-17 Preparing to support both 4-Pin and 3-Pin Fans.
    [fan-controller-4pin-esp32-c3.factory.yaml, fan-controller-4pin-esp32-c3.yaml]
2026-03-17 Update Install buttons for 4-Pin and 3-Pin fans
2026-03-17 Update PCB to Rev A 5V power supply now uses TPS613222A. Different package with correct voltage. Replace fan interface ESD diodes with dual TVS in SOT-23 package. Shutdown on LM76202 can be used to r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
    [esphome-fan-controller-B_Cu.gbr, esphome-fan-controller-B_Mask.gbr, esphome-fan-controller-B_Silkscreen.gbr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]
